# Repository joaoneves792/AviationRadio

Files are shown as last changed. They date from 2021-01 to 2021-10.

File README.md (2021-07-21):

# AviationRadio
Aviation inspired radio using an Arduino + Si4844

It can receive broadcast FM and VHF AM, including the civil aviation airband, (using a downconverter based on SA612 + Si5351)

It also works as a flight sim peripheral, currently with an X-Plane 11 plugin (Linux only) for controlling the plane radios.

# TODO 
- documentation
- BOM
- Redesign the 3D printed box (current printed version is very rough quality)

# Initial working prototype pictures

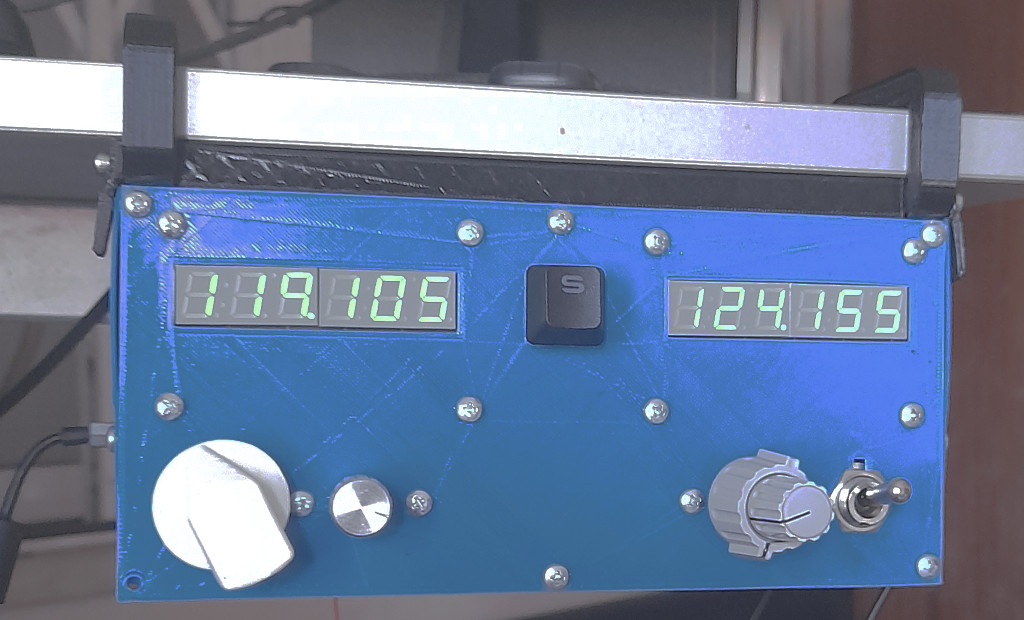
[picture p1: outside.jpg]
outside


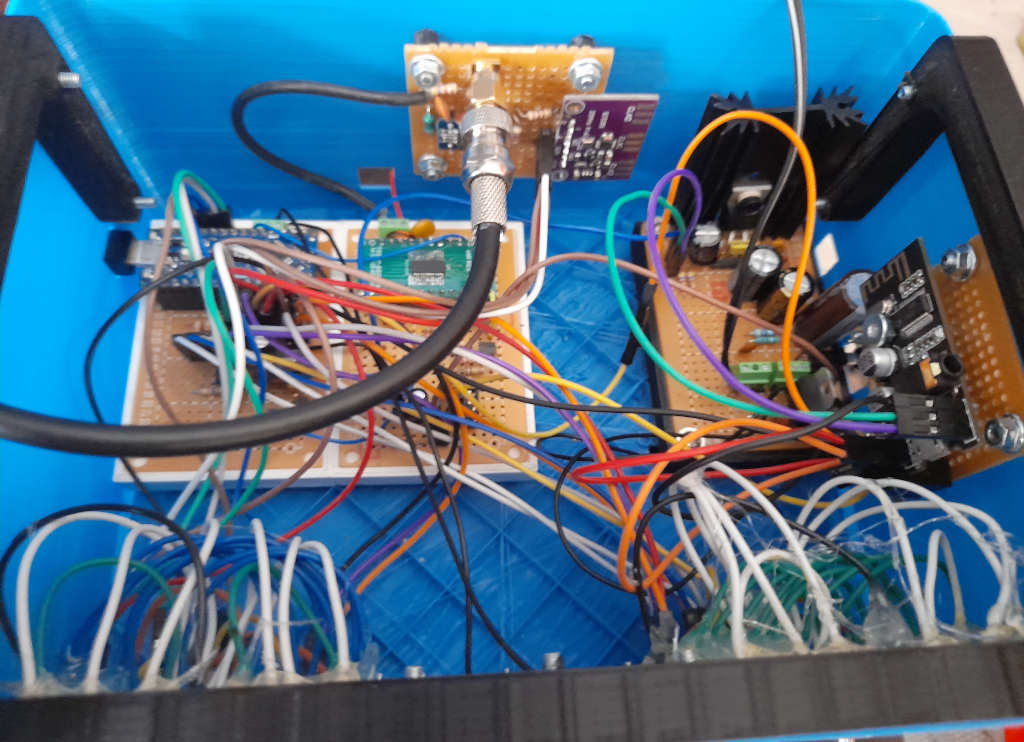
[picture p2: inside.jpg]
inside


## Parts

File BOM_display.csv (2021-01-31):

Name | Type | Value | Quantity | Unit Price | Quant Price | Total BOM Cost
Q1, Q2, Q3, Q4, Q5, Q6 | TO92 | 2N7000 | 6 | 0,10 ? | 0,60 ? | 11,19 ?
IC3 | DIP8 | ATTiny85 | 1 | 2,68 ? | 2,68 ?
Connector1 | Connector: Pin Strip (100 mil) (4 pins) | Connector1 | 1 | 0,10 ? | 0,10 ?
R1 | AngledResistor | 220 | 1 | 0,02 ? | 0,02 ?
IC1, IC2 | DIP16 | 74HC595 | 2 | 0,71 ? | 1,42 ?
7S1, 7S2 | 7SEG | HDSP-433G | 2 | 2,60 ? | 5,20 ?
Board | PerfBoard | PerfBoard | 1 | 1,17 ? | 1,17 ?

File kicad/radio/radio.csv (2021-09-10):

Reference | Quantity | Value
A1 | 1 | Arduino_Nano_Every
C1 C2 C3 C4 C11 | 5 | 10nF
C10 | 1 | 1nF
C12 | 1 | 1uF
C13 | 1 | 100uF
C5 C8 | 2 | 100nF
C6 C7 | 2 | 22pF
C9 | 1 | 470nF
J1 | 1 | SDA
J10 | 1 | GND2/+5v
J2 | 1 | SCL
J3 J4 | 2 | +5v
J5 | 1 | GND1/+12v
J6 | 1 | Audio Out
J7 | 1 | Antennas
J8 J9 | 2 | GND2
JP1 | 1 | Jumper
L1 | 1 | 56nH
Q1 Q2 | 2 | 2N7000
Q3 | 1 | 2N2222
R1 R2 R3 R4 R5 R6 R7 R8 | 8 | 10k
R10 | 1 | 2k
R11 R13 | 2 | 100k
R12 | 1 | 220k
R14 | 1 | 200
R15 | 1 | 10
R16 | 1 | 470
R9 | 1 | 1k
RV1 | 1 | Volume_POT
SW1 | 1 | Cherry MX
SW2 | 1 | SW_Mode_Selection
SW3 SW4 | 1 | ELMA E37
U1 | 1 | Si4844
U2 | 1 | 24LC08
U3 | 1 | 4N35
Y1 | 1 | 32kHz | ~

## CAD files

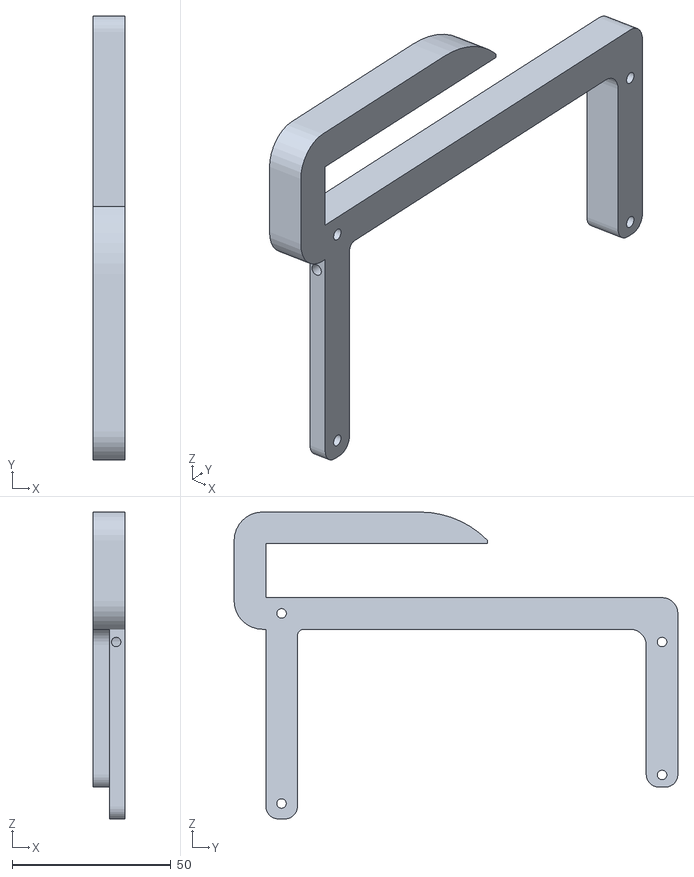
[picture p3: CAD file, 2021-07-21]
3dmodels/support_right.stl
10.0 x 140.0 x 96.8

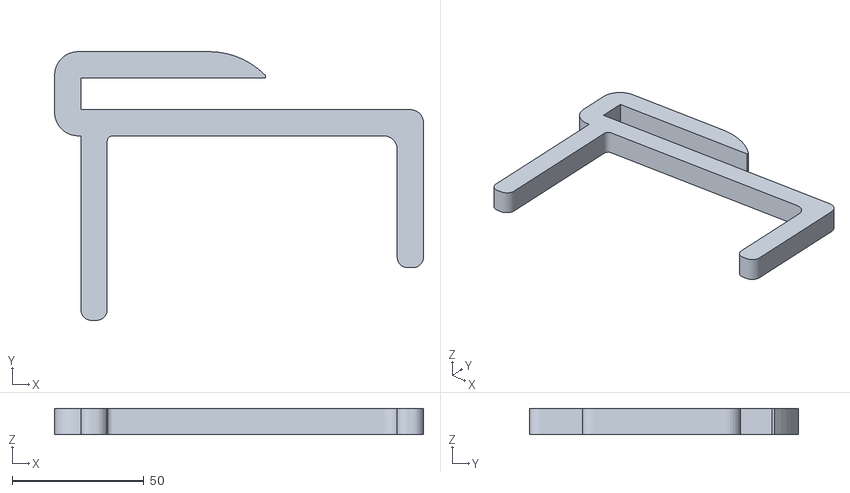
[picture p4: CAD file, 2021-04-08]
3dmodels/supports_cad.stl
140.0 x 102.0 x 10.0

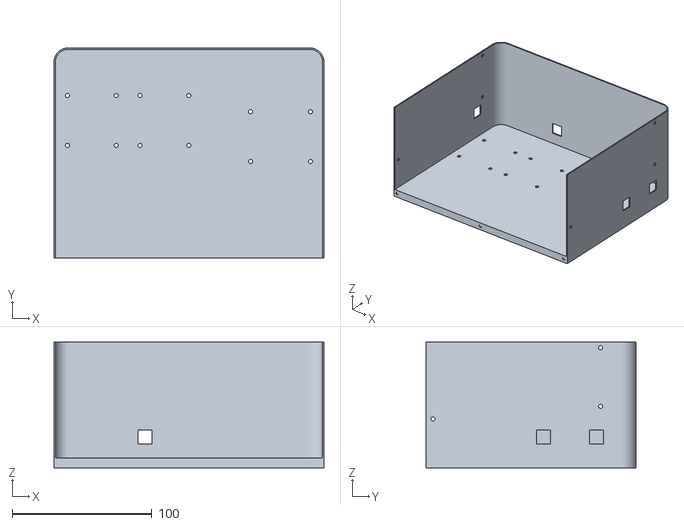
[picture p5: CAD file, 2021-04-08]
3dmodels/box.stl
193.2 x 150.3 x 90.0

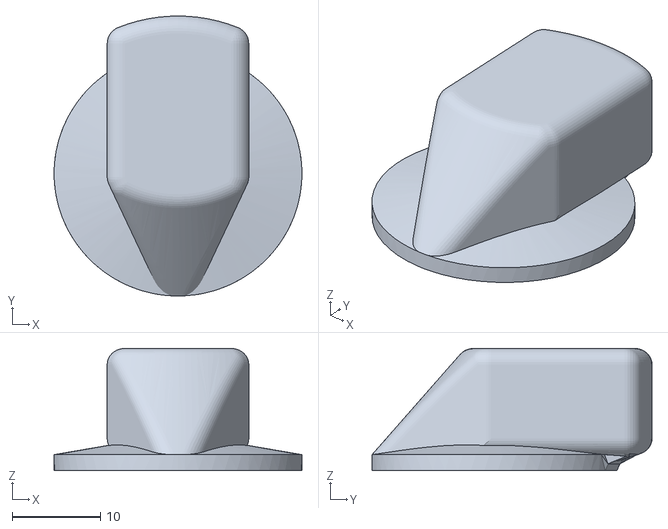
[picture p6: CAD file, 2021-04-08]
3dmodels/ECAM2.stl
28.1 x 31.8 x 13.9

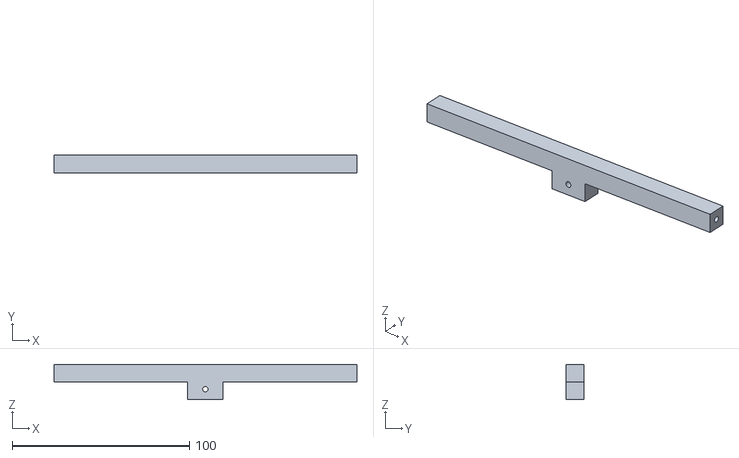
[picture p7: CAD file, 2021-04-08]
3dmodels/strut.stl
171.1 x 10.0 x 19.9

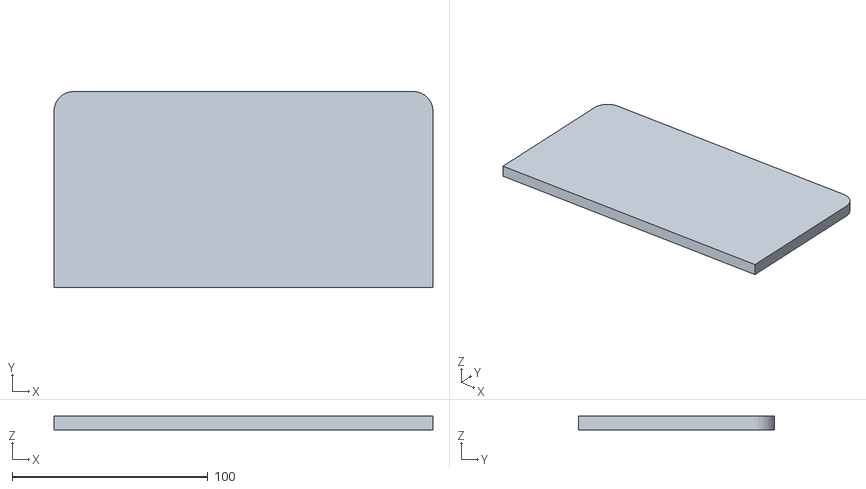
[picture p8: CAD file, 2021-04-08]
3dmodels/boxCAD.stl
193.5 x 100.0 x 7.00

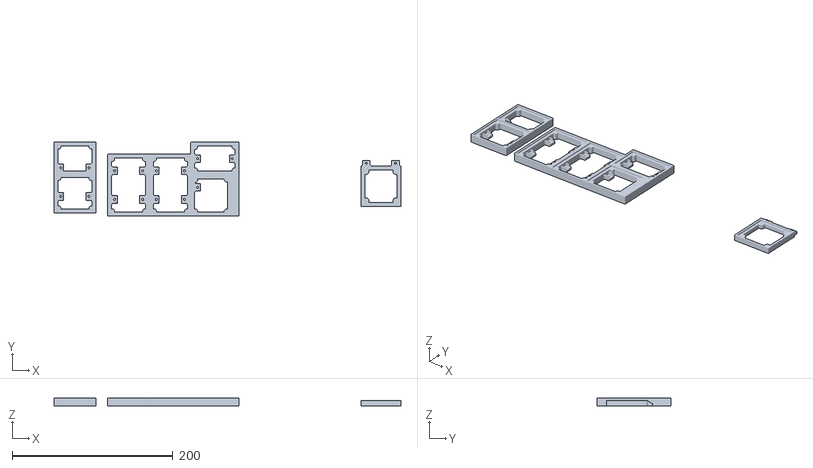
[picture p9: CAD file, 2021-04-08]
3dmodels/PCBholder_WIP.stl
431.3 x 92.3 x 10.0

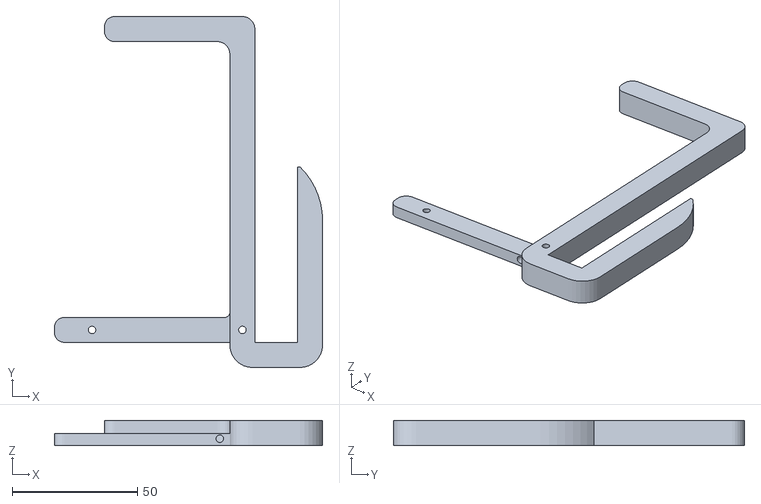
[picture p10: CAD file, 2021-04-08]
3dmodels/supports_blender.stl
107.0 x 140.0 x 10.0

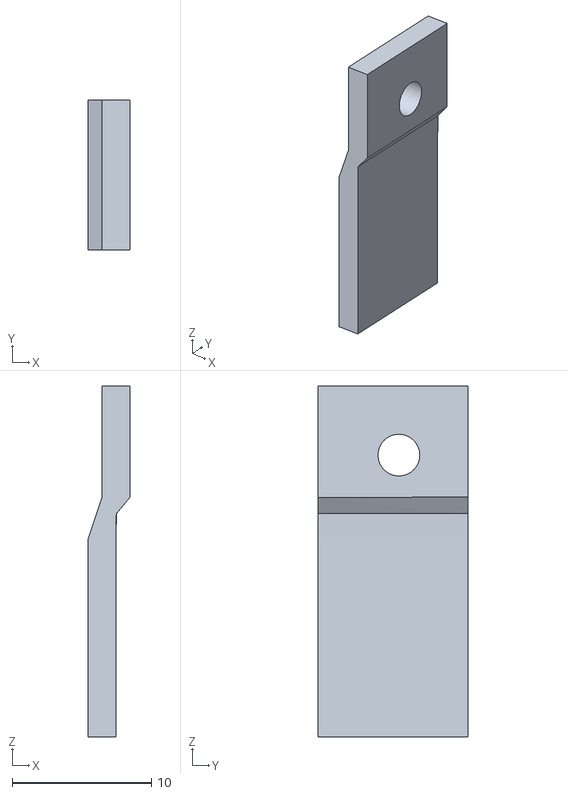
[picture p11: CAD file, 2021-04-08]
3dmodels/Clip.stl
3.00 x 10.8 x 25.2

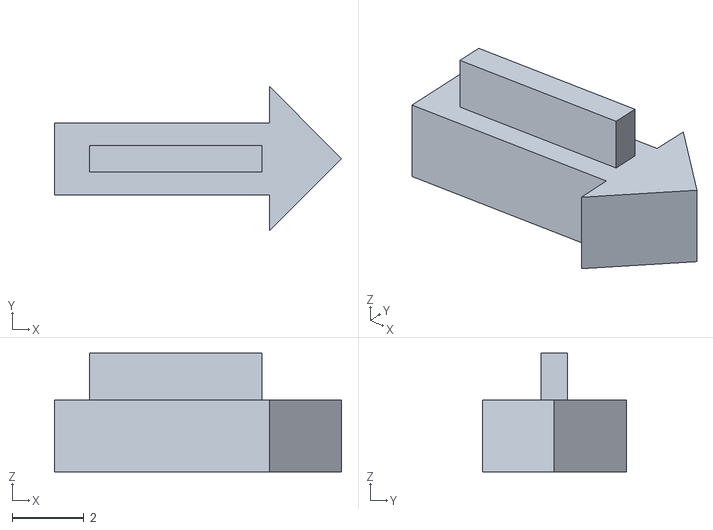
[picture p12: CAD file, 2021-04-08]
3dmodels/Arrow.stl
7.99 x 4.02 x 3.31

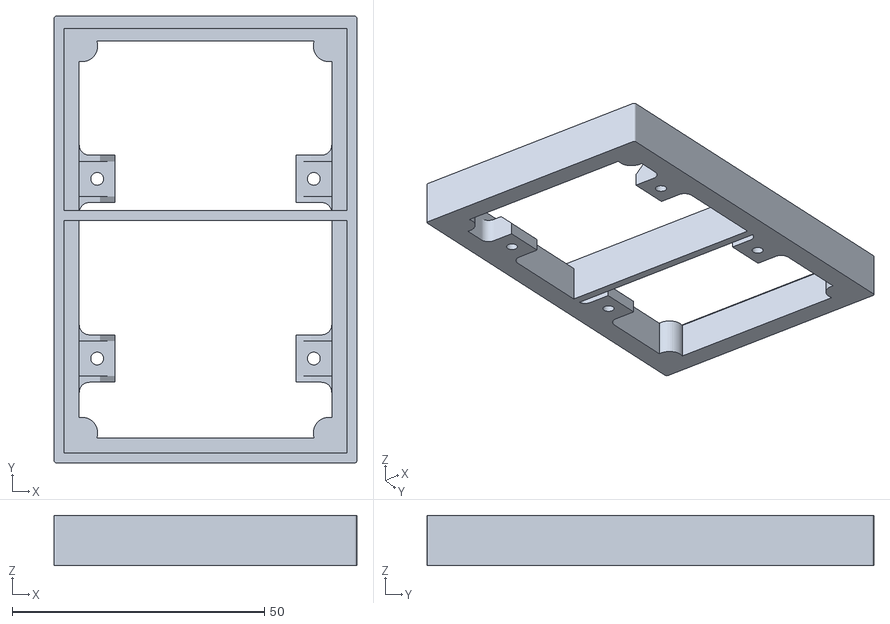
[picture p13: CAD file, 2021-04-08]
3dmodels/PCBholder_AMP_POWER.stl
60.0 x 88.6 x 10.0

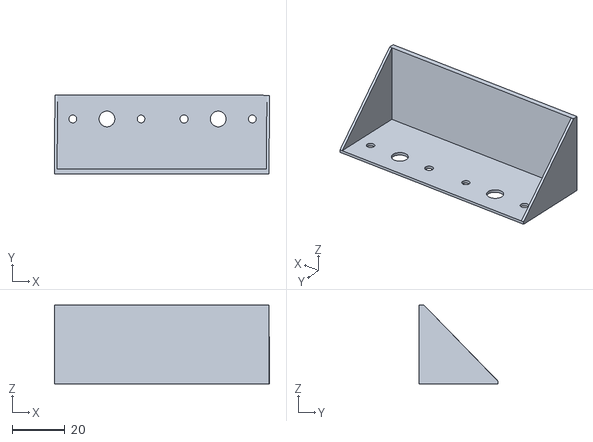
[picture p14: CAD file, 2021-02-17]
3dmodels/testPanel.stl
81.9 x 30.2 x 29.9

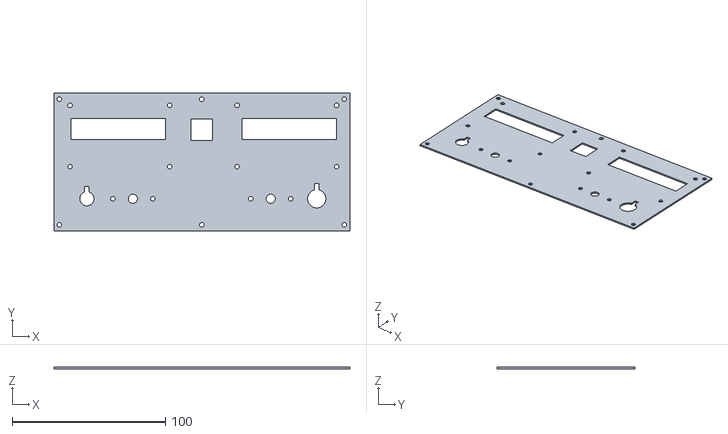
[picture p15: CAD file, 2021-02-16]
3dmodels/frontPanelV2.stl
193.2 x 90.0 x 1.00

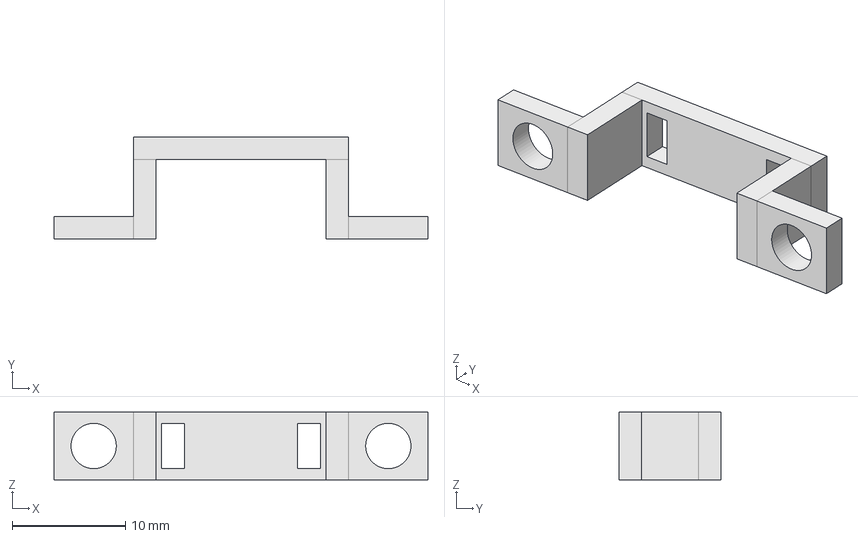
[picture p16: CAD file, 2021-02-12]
3dmodels/EncoderSupport .FCStd
33.0 x 9.00 x 6.00 mm

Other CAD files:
3dmodels/Supports2.FCStd
3dmodels/Supports.FCStd
3dmodels/potSupport.FCStd
3dmodels/MXterst.FCStd
3dmodels/All.blend
3dmodels/EncoderSupport.stl
3dmodels/FrontPanelV1.FCStd
3dmodels/M3Spacer.blend
3dmodels/M3_6mmHex.stl
3dmodels/MXtest.stl
3dmodels/VK_MXtest.3mf
3dmodels/displayTest.FCStd
3dmodels/displayTest.stl
3dmodels/frontPanelV1.stl
3dmodels/potSupport.blend
3dmodels/potSupport.stl

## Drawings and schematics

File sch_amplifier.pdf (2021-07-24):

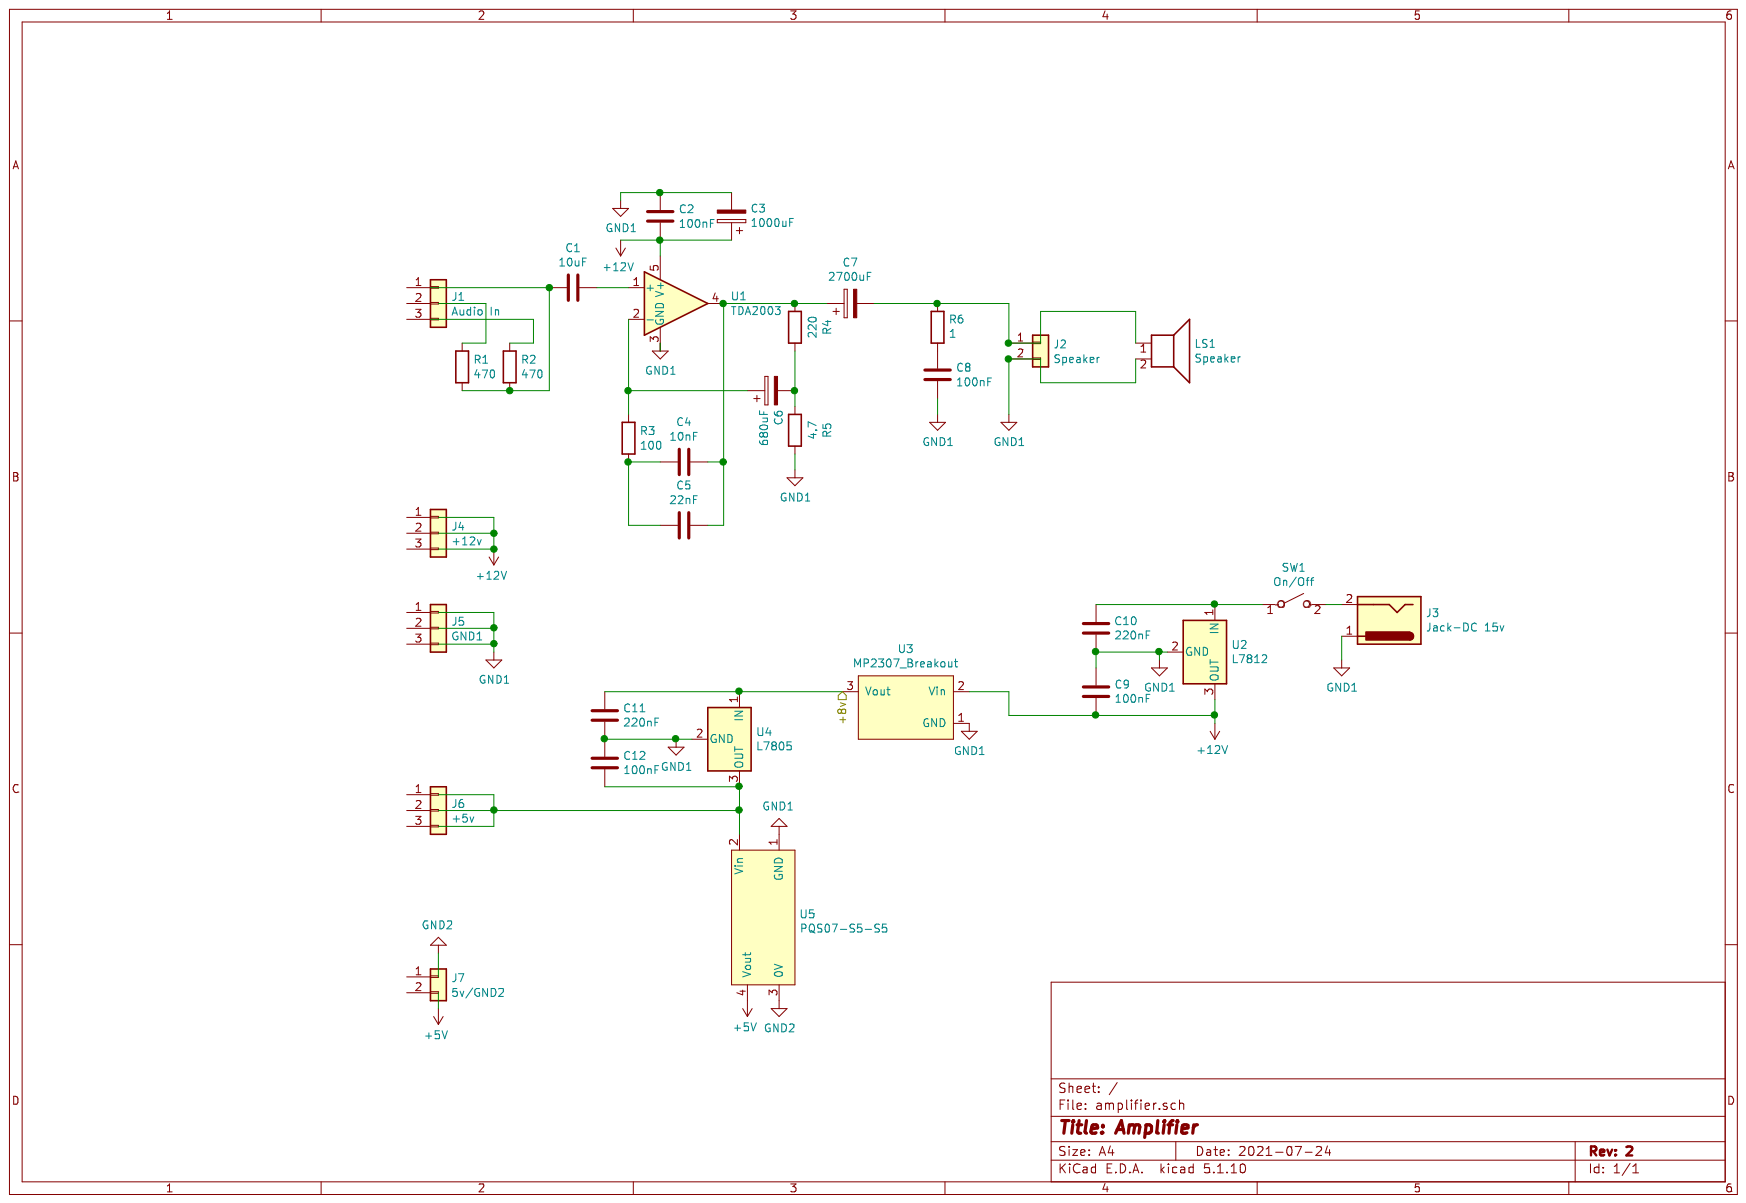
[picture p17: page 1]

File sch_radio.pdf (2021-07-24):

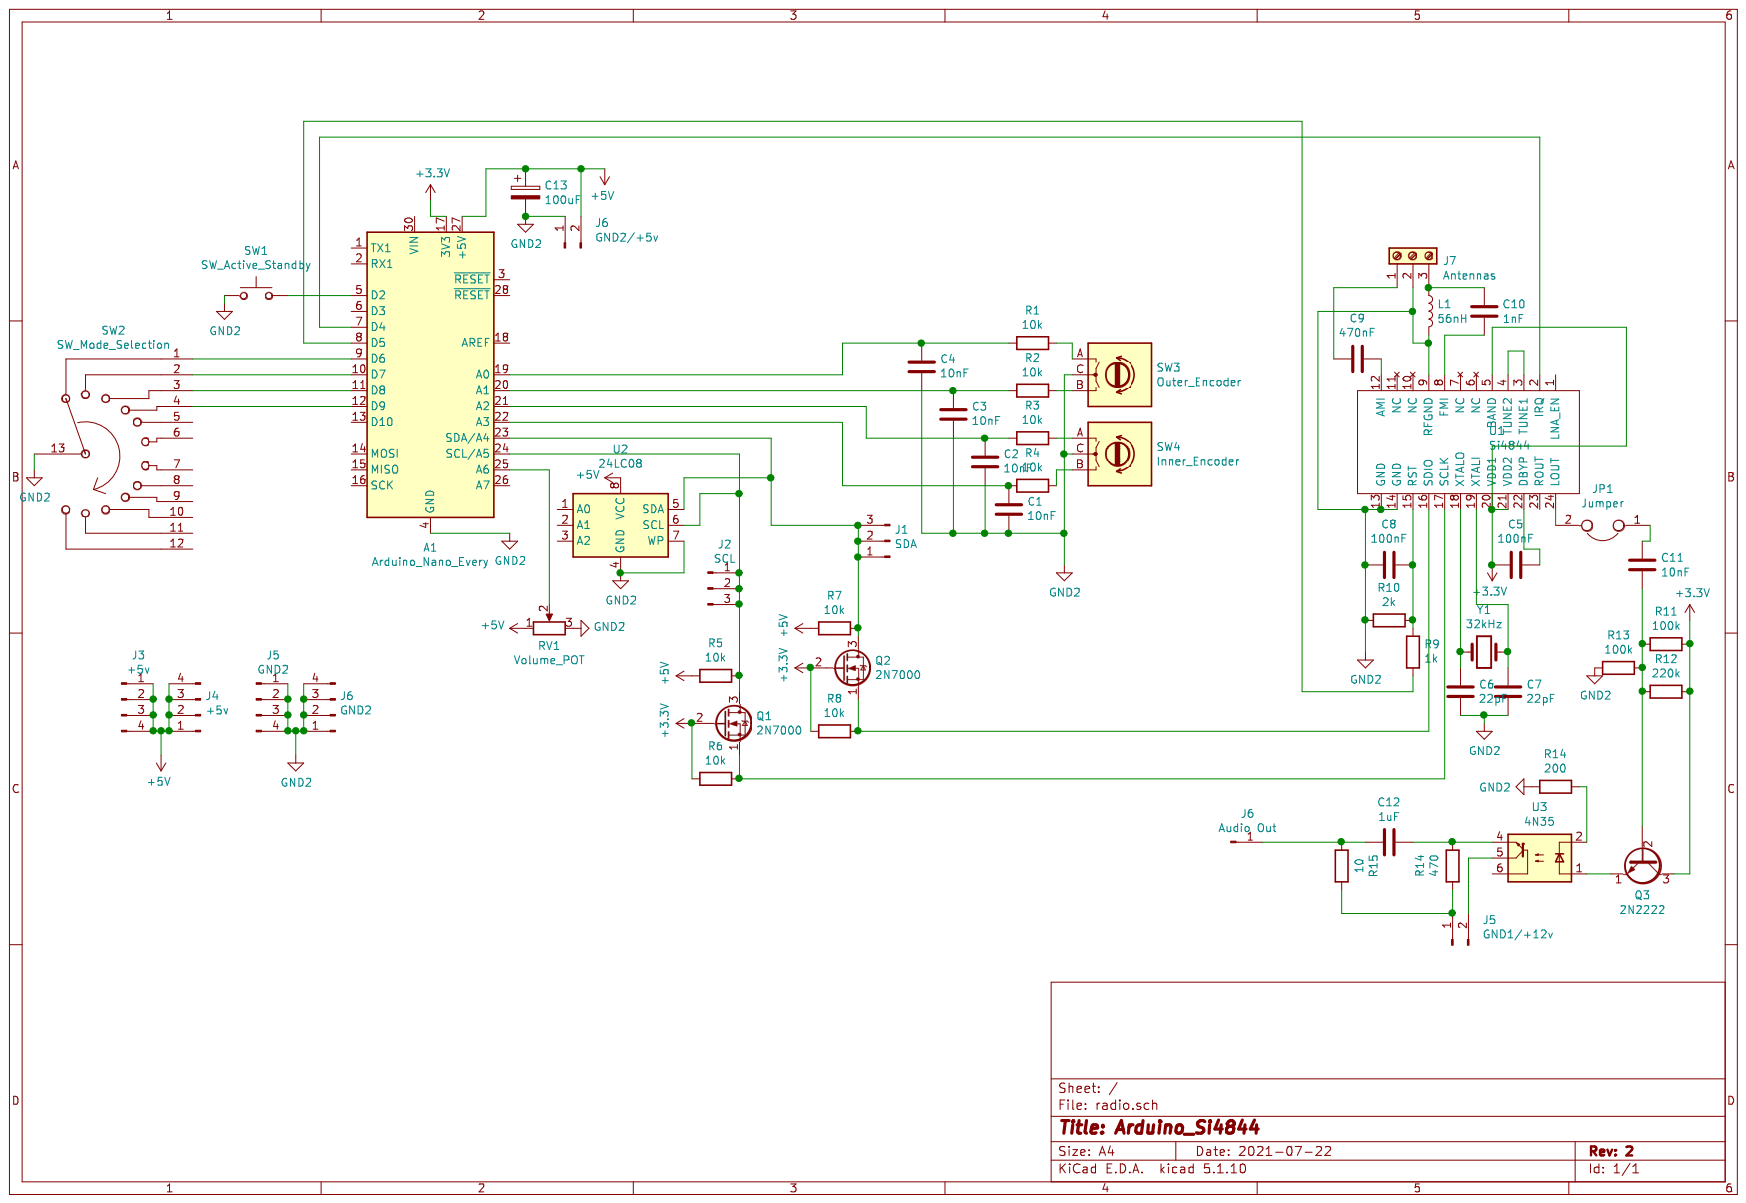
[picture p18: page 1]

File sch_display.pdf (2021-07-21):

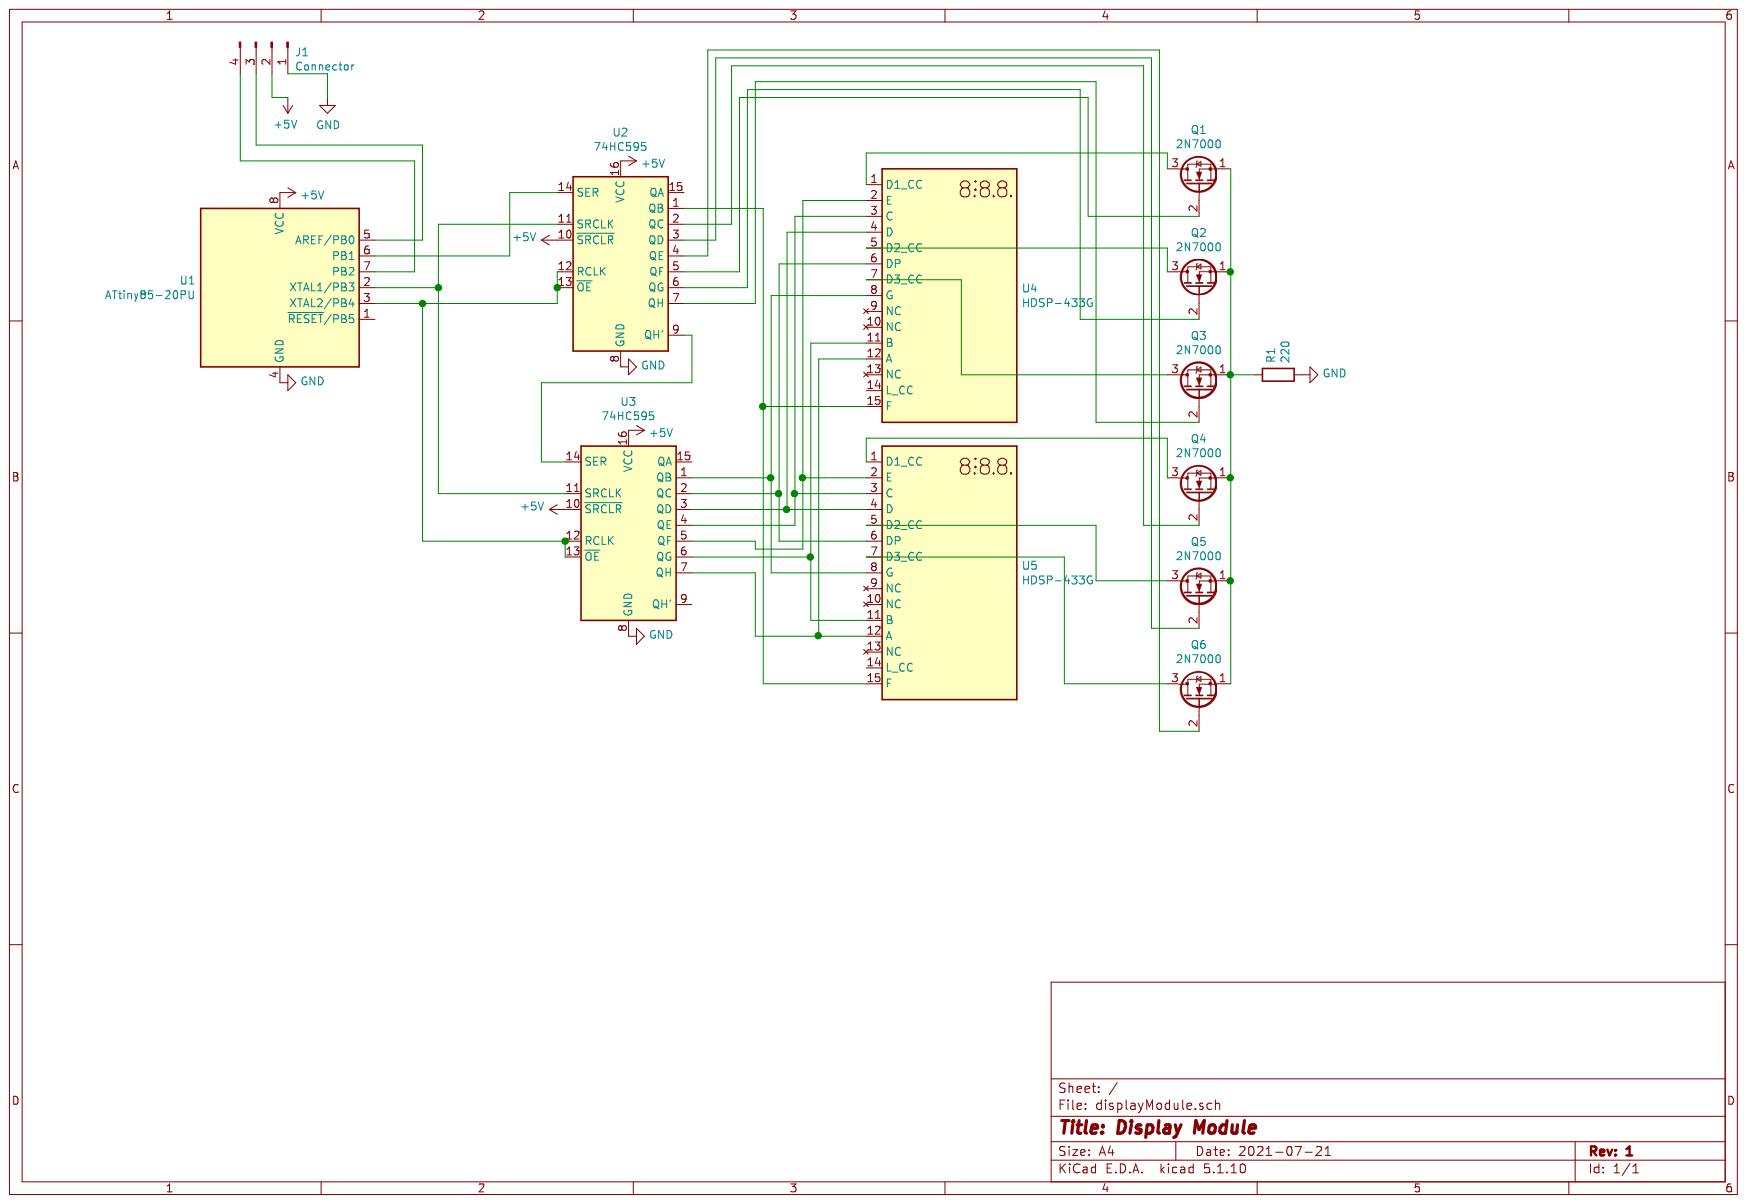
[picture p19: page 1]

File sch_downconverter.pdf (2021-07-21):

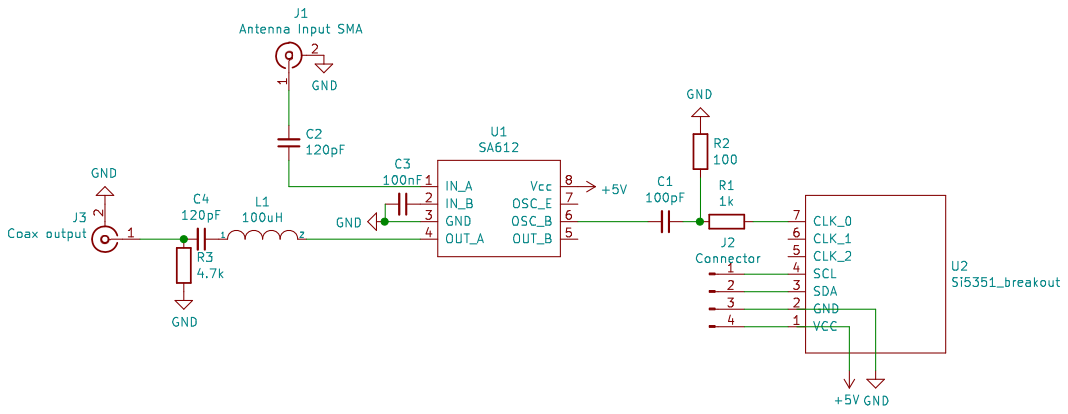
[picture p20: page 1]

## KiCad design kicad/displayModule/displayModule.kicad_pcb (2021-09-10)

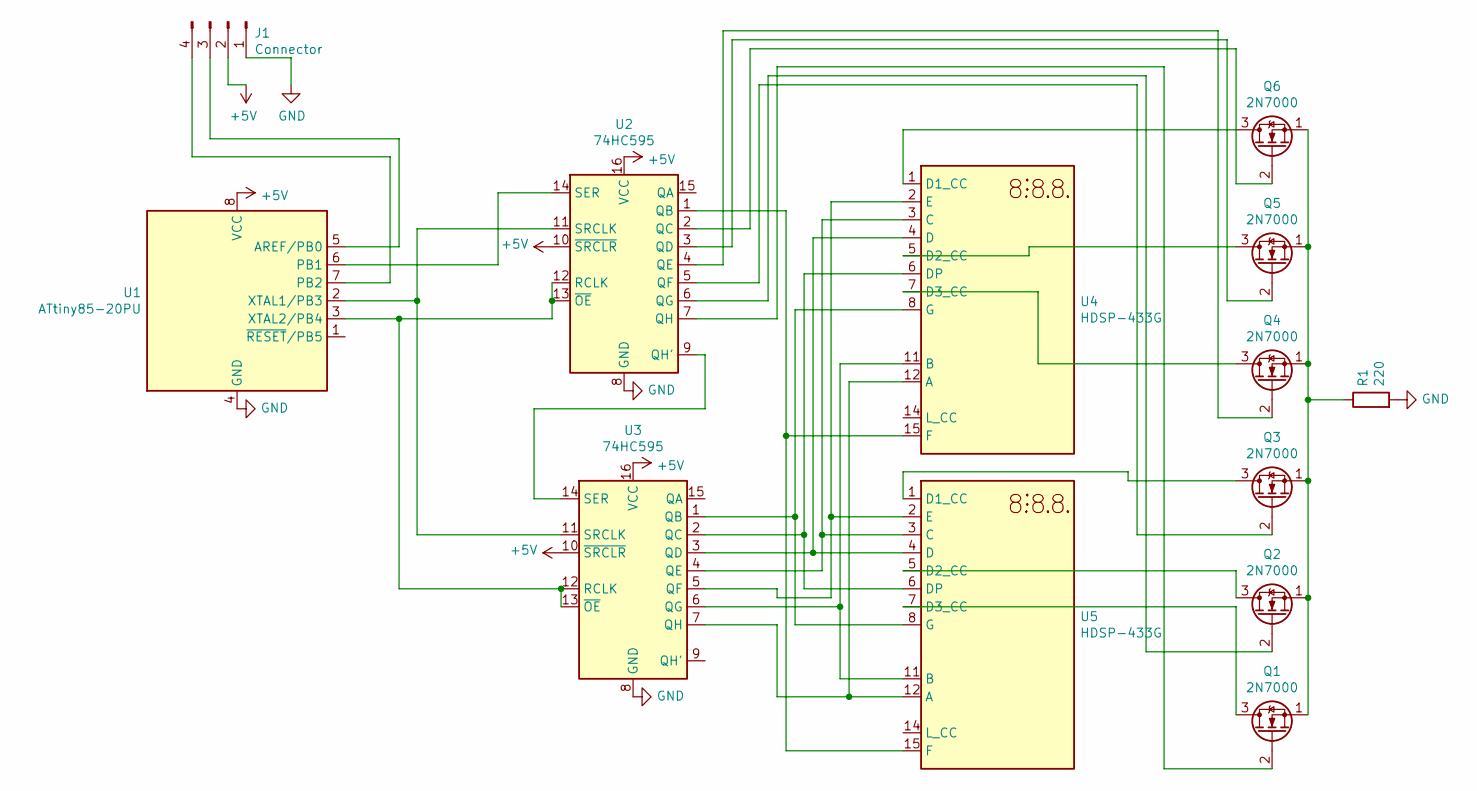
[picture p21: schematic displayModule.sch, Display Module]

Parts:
J1: Connector; PinHeader_1x04_P2.54mm_Vertical
Q1, Q2, Q3, Q4, Q5, Q6: 2N7000; TO-92_Inline_Wide
R1: 220; R_Axial_DIN0207_L6.3mm_D2.5mm_P7.62mm_Horizontal
U1: ATtiny85-20PU; DIP-8_W7.62mm
U2, U3: 74HC595; DIP-16_W7.62mm
U4, U5: HDSP-433G

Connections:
+5V: J1.2, U1.8 (VCC), U2.10 (~SRCLR), U2.16 (VCC), U3.10 (~SRCLR), U3.16 (VCC)
GND: J1.1, R1.2, U1.4 (GND), U2.8 (GND), U3.8 (GND)
unnamed: J1.3, U1.5 (AREF/PB0)
unnamed: J1.4, U1.7 (PB2)
unnamed: Q1.1 (S), Q2.1 (S), Q3.1 (S), Q4.1 (S), Q5.1 (S), Q6.1 (S), R1.1
unnamed: Q1.2 (G), U2.7 (QH)
unnamed: Q1.3 (D), U5.7 (D3_CC)
unnamed: Q2.2 (G), U2.6 (QG)
unnamed: Q2.3 (D), U5.5 (D2_CC)
unnamed: Q3.2 (G), U2.5 (QF)
unnamed: Q3.3 (D), U5.1 (D1_CC)
unnamed: Q4.2 (G), U2.4 (QE)
unnamed: Q4.3 (D), U4.7 (D3_CC)
unnamed: Q5.2 (G), U2.3 (QD)
unnamed: Q5.3 (D), U4.5 (D2_CC)
unnamed: Q6.2 (G), U2.2 (QC)
unnamed: Q6.3 (D), U4.1 (D1_CC)
unnamed: U1.2 (XTAL1/PB3), U2.11 (SRCLK), U3.11 (SRCLK)
unnamed: U1.3 (XTAL2/PB4), U2.12 (RCLK), U2.13 (~OE), U3.12 (RCLK), U3.13 (~OE)
unnamed: U1.6 (PB1), U2.14 (SER)
unnamed: U2.1 (QB), U4.15 (F), U5.15 (F)
unnamed: U2.9 (QH'), U3.14 (SER)
unnamed: U3.1 (QB), U4.8 (G), U5.8 (G)
unnamed: U3.2 (QC), U4.6 (DP), U5.6 (DP)
unnamed: U3.3 (QD), U4.4 (D), U5.4 (D)
unnamed: U3.4 (QE), U4.3 (C), U5.3 (C)
unnamed: U3.5 (QF), U4.2 (E), U5.2 (E)
unnamed: U3.6 (QG), U4.11 (B), U5.11 (B)
unnamed: U3.7 (QH), U4.12 (A), U5.12 (A)

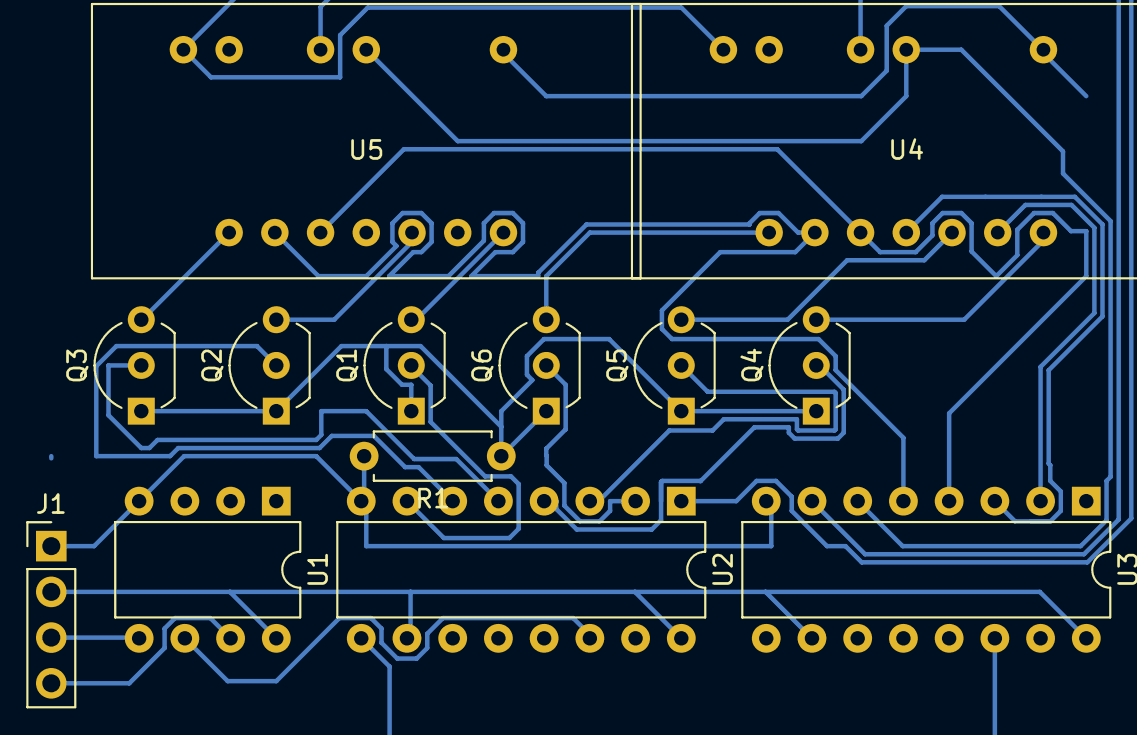
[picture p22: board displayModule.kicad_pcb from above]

Board: 2 copper layers, 13 parts (0 on the bottom side), 29 nets.

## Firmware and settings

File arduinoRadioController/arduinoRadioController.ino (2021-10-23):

#include <Arduino.h>
#include <Wire.h>
#include "si5351.h"
#include "./Encoder.h"
#include <avr/io.h>

#define buttonPin 2 //Pin connected to active/standby button
#define volumePotPin A6
#define FMselectPin 6
#define COMselectPin 7
#define NAVselectPin 8
#define ATDD_RESET_PIN 5
#define ATDD_IRQ_PIN 4

#define OUTER_ENCODER_A_PIN 14
#define OUTER_ENCODER_B_PIN 17
#define INNER_ENCODER_A_PIN 16
#define INNER_ENCODER_B_PIN 15

#define SLAVE_ACTIVE_ADDRESS 0x12
#define SLAVE_STNDBY_ADDRESS 0x13
#define ATDD_ADDRESS 0x11
#define EPROM_ADDRESS 0x50
#define LO_ADDRESS 0x60

#define ACTIVE_MEMSLOT 0
#define STANDBY_MEMSLOT 1

#define FM_MODE 0
#define AM_MODE 1
#define SW_MODE 2
#define COM_MODE 3
#define NAV_MODE 4
#define COM2_MODE 5

#define ENCODER_CONTROLLS_STANDBY
//#undef ENCODER_CONTROLLS_STANDBY

#define RX_HARD_MUTE 0x4001
#define RX_BASS_TREBLE 0x4002
#define AM_SOFT_MUTE_SLOPE 0x3301
#define AM_SOFT_MUTE_MAX_ATTENUATION 0x3302
#define AM_SOFT_MUTE_SNR_THRESHOLD 0x3303
#define AM_SOFT_MUTE_RATE 0x3300
#define AM_SQUELCH_SNR_THRESHOLD 7


// IF in kHz
#define IF 1200
#define LO_PPM 146391

const unsigned char digitSegments[16]  = {
                 0b11111100,//0
                 0b01100000,//1
                 0b11011010,//2
                 0b11110010,//3
                 0b01100110,//4
                 0b10110110,//5
                 0b00111110,//6
                 0b11100000,//7
                 0b11111110,//8
                 0b11100110,//9
                 0b11101110,//A
                 0b00111110,//B
                 0b10011100,//C 
                 0b01111010,//D 
                 0b10011110,//E 
                 0b10001110,//F
                };

typedef struct{
  uint16_t MHz;
  uint16_t kHz;
} freq;
#define SET_FREQ(FREQ, STRUCT) {STRUCT.MHz = FREQ/1000; STRUCT.kHz = FREQ%1000;}
#define GET_FREQ(STRUCT) ((uint32_t)(STRUCT.MHz)*1000+STRUCT.kHz)

struct setPropertyQueueElement;
struct setPropertyQueueElement{
  uint16_t property;
  uint16_t value;
  struct setPropertyQueueElement* next;
};


/*-----------------------*/
//Global variables (shared memory between all threads)
freq shm_activeFreq;
freq shm_standbyFreq;
struct setPropertyQueueElement* shm_propertiesQueue = NULL;
uint8_t shm_bandmode = 0;
volatile uint8_t shm_ATDDIRQ = 0;
uint8_t shm_ATDDOperational = 0;
uint8_t shm_ATDDReady = 0;
uint8_t shm_AMStationDetected = 0;
uint8_t shm_scanInProgress = 0;
Si5351 shm_si5351(LO_ADDRESS);
/*-----------------------*/

/*------------------------*/
Encoder* outerEncoder = NULL;
Encoder* innerEncoder = NULL;
/*------------------------*/

/*------------------------*/
/* property queue*/
void queueProperty(uint16_t property, uint16_t value) {
  struct setPropertyQueueElement* prev = shm_propertiesQueue;
  while(prev && prev->next){
    prev = prev->next;
  }
  struct setPropertyQueueElement* prop = (struct setPropertyQueueElement*) malloc(sizeof(struct setPropertyQueueElement));
  prop->property = property;
  prop->value = value;
  prop->next = NULL;
  if(NULL == prev){
    shm_propertiesQueue = prop;
  }else{
    prev->next = prop;
  }
 }
/*-----------------------*/

/*-----------------------*/
//Thread handling
struct thread;
struct thread {
  void (*function)();
  short target;
  unsigned long lastExecuted;
  struct thread* next;
};

struct thread* threads;

struct thread* createNewThread(void (*function)(), short target){
  struct thread* newThread = (thread*)malloc(sizeof(thread));

  newThread->function = function;
  newThread->target = target;
  newThread->lastExecuted = 0;
  newThread->next =NULL;

  return newThread;  
}

void insertThread(struct thread* t){
  t->next = threads;
  threads = t;
}
/*-----------------------*/

/*-----------------------*/
//EEPROM commands

void EEPROMwrite(uint32_t freq, uint8_t mode, uint8_t active){
  uint8_t address = mode*8+active*4;
  do{
    Wire.beginTransmission(EPROM_ADDRESS);
    Wire.write(address);
    Wire.write((freq >> 24) & 0xff);
    Wire.write((freq >> 16) & 0xff);
    Wire.write((freq >> 8) & 0xff);
    Wire.write(freq & 0xff);
  }while(Wire.endTransmission());
}

uint32_t EEPROMread(uint8_t mode, uint8_t active){
  uint8_t address = mode*8+active*4;
  do{
    Wire.beginTransmission(EPROM_ADDRESS);
    Wire.write(address);
  }while(Wire.endTransmission(false));
  Wire.requestFrom(EPROM_ADDRESS, 4);
  while(Wire.available() < 4){delay(5);}
  uint32_t f =   ((uint32_t)Wire.read() << 24) 
          |((uint32_t)Wire.read() << 16) 
          |((uint32_t)Wire.read() << 8) 
          | Wire.read();
  return f;
}

/*-----------------------*/


/*-----------------------*/
//ATDD commands

uint16_t ATDD_FREQ_TO_INT_FM(uint16_t ATDD_freq){
  return ((ATDD_freq & 0x0f)+((ATDD_freq & 0xf0)>>4)*10+((ATDD_freq & 0xf00)>>8)*100+((ATDD_freq & 0xf000)>>12)*1000)*10;
}
uint16_t ATDD_FREQ_TO_INT_AM(uint16_t ATDD_freq){
  return ((ATDD_freq & 0x0f)+((ATDD_freq & 0xf0)>>4)*10+((ATDD_freq & 0xf00)>>8)*100+((ATDD_freq & 0xf000)>>12)*1000);
}


void ATDD_SET_PROPERTY(uint16_t propertyNumber, uint16_t parameter)
{
  if(!shm_ATDDOperational || !shm_ATDDReady)
    return;

  shm_ATDDReady = 0;

#define SET_PROPERTY 0x12
    Wire.beginTransmission(ATDD_ADDRESS);
    Wire.write(SET_PROPERTY);
    Wire.write(0x00);
    Wire.write(propertyNumber >> 8); // Send property - High byte - most significant first
    Wire.write(propertyNumber & 0xff);  // Send property - Low byte - less significant after
    Wire.write(parameter >> 8);    // Send the argments. High Byte - Most significant first
    Wire.write(parameter & 0xff);     // Send the argments. Low Byte - Less significant after
    Wire.endTransmission();

    do{
      delay(2);
      ATDD_GET_STATUS();
    }while(!shm_ATDDReady);
}


void ATDD_RESET(){
  shm_ATDDOperational = 0;
  shm_ATDDReady = 0;
  digitalWrite(LED_BUILTIN, LOW);
  digitalWrite(ATDD_RESET_PIN, LOW);
  delay(200);
  digitalWrite(ATDD_RESET_PIN, HIGH);
}

void ATDD_POWERUP(){
#define ATDD_POWER_UP_CMD 0xE1
    uint8_t band;
    uint8_t chspc;

    if(shm_bandmode != FM_MODE && shm_bandmode != AM_MODE && shm_bandmode != SW_MODE){
      band = 2;
      chspc = 1;
    }
    

    if(shm_bandmode == FM_MODE){
      band = 2;
      chspc = 1;
    }
    else if (shm_bandmode == AM_MODE){
      band = 20;
      chspc = 1;
      //band = 25; //SW bandmode
      //chspc = 5;
    }

    shm_ATDDReady = 0;

    uint16_t freq = (GET_FREQ(shm_activeFreq)/((shm_bandmode==FM_MODE)?10:1));

    uint8_t args[7];

    args[0] = 0x80; //Enable crystal
    //args[0] = 0x0; //Disable crystal
    args[0] |= band;
    if(shm_bandmode == FM_MODE){
      args[1] = (freq-chspc) >> 8;
      args[2] = (freq-chspc) & 0xff;

      args[3] = (freq) >> 8;
      args[4] = (freq) & 0xff;
    }else if(shm_bandmode == AM_MODE){
      args[1] = (IF-(50*chspc)) >> 8;
      args[2] = (IF-(50*chspc)) & 0xff;

      args[3] = (IF) >> 8;
      args[4] = (IF) & 0xff;

    }

    args[5] = chspc;

    args[6] = 0x1 << 6;

    Wire.beginTransmission(ATDD_ADDRESS);
    Wire.write(ATDD_POWER_UP_CMD);
    Wire.write(args[0]);
    Wire.write(args[1]);
    Wire.write(args[2]);
    Wire.write(args[3]);
    Wire.write(args[4]);
    Wire.write(args[5]);
    Wire.write(args[6]);
    Wire.endTransmission();
    delay(3);//the host controller needs to wait for 2 ms before polling response byte CTS bit or reading the response directly.

    //ATDD_SET_PROPERTY(0x0201, 0x7c9c); //Set clock to 31900
    //ATDD_SET_PROPERTY(0x0202, 500); //Set divider to 500
    
}

void ATDD_GET_STATUS(){
#define ATDD_GET_STATUS_CMD (0xE0)
#define CTS_BIT_MASK (1 << 7) 
#define HOSTRST_BIT_MASK (1 << 6)
#define HOSTPWRUP_BIT_MASK (1 << 5)
#define INFORDY_BIT_MASK (1 << 4)
#define STATION_BIT_MASK (1 << 3)
#define STEREO_BIT_MASK (1 << 2)
#define BCFG1_BIT_MASK (1 << 1)
#define BCFG0_BIT_MASK (1 << 0)
#define GET_BAND_MODE(resp) ((resp & 0xC0) >> 6)
#define GET_BANDIDX(resp) (resp & 0x3f)


    Wire.beginTransmission(ATDD_ADDRESS);
    Wire.write(ATDD_GET_STATUS_CMD);
    Wire.endTransmission();
    delay(3);//the host controller needs to wait for 2 ms before polling response byte CTS bit or reading the response directly.
    if(!Wire.requestFrom(ATDD_ADDRESS, 4))
      return;
    uint8_t status = Wire.read();
    uint8_t resp1 = Wire.read();
    uint8_t resp2 = Wire.read();
    uint8_t resp3 = Wire.read();
    
    if(status & HOSTRST_BIT_MASK){
      Serial.println("ATDD: Requested reset");
      ATDD_RESET();
      return;
    }

    if(status & HOSTPWRUP_BIT_MASK && (shm_bandmode == FM_MODE || shm_bandmode == AM_MODE)){
      Serial.println("ATDD: Requested powerup");
      ATDD_POWERUP();
      return;
    }
    
    if(status & INFORDY_BIT_MASK){
      if(!shm_ATDDOperational){
        if(shm_bandmode == FM_MODE){
          queueProperty(RX_BASS_TREBLE, 1);
          queueProperty(RX_HARD_MUTE, 0x0);
        }else if(shm_bandmode == AM_MODE){
          queueProperty(RX_BASS_TREBLE, 1);
          queueProperty(RX_HARD_MUTE, 0x0);
        }
      }
      shm_ATDDOperational = 1;
      digitalWrite(LED_BUILTIN, HIGH);
      Serial.print("ATDD: Frequency: ");
      if(shm_bandmode == FM_MODE)
        Serial.print(ATDD_FREQ_TO_INT_FM(((uint16_t)resp2 << 8) | resp3));
      else
        Serial.print(ATDD_FREQ_TO_INT_AM((uint16_t)resp2 << 8 | resp3));
      
      Serial.print("KHz");
      Serial.print(" Station ");
      if(shm_scanInProgress && (status & STATION_BIT_MASK)){
        shm_scanInProgress = 0;
      }
      (status & STATION_BIT_MASK)?Serial.print("valid"):Serial.print("invalid");
      if(!shm_AMStationDetected && (status & STATION_BIT_MASK)){
        shm_AMStationDetected = 1;
        //Set squelch
        queueProperty(AM_SOFT_MUTE_SNR_THRESHOLD, AM_SQUELCH_SNR_THRESHOLD);
        queueProperty(AM_SOFT_MUTE_SLOPE, 5);
        queueProperty(AM_SOFT_MUTE_MAX_ATTENUATION, 63); 
        queueProperty(AM_SOFT_MUTE_RATE, 255);
      }

      Serial.print(" Stereo ");
      (status & STEREO_BIT_MASK)?Serial.print("on"):Serial.print("off");
      Serial.print(" Band: ");
      if(GET_BAND_MODE(resp1) == 0)
        Serial.print("FM");
      if(GET_BAND_MODE(resp1) == 1)
        Serial.print("AM");
      if(GET_BAND_MODE(resp1) == 2)
        Serial.print("SW");
      Serial.println("");
      
    }
    shm_ATDDReady = (status & CTS_BIT_MASK);
    
}

void ATDDIHR(){
  shm_ATDDIRQ=1;
  //Serial.println("IRQ");
} 


void onFreqChange(){
  if(shm_bandmode == AM_MODE){
    shm_AMStationDetected = 0;
    //Set defaults
    queueProperty(AM_SOFT_MUTE_SNR_THRESHOLD, 0x0008);
    queueProperty(AM_SOFT_MUTE_SLOPE, 0x0001);
    queueProperty(AM_SOFT_MUTE_MAX_ATTENUATION, 0x0010); 
    queueProperty(AM_SOFT_MUTE_RATE, 0x0040);
  }

  printChange();
}

/*-----------------------------*/
void printChange(){
  Serial.print("AVRADIO ");
  Serial.print("A:");
  Serial.print(GET_FREQ(shm_activeFreq));
  Serial.print(" S:");
  Serial.print(GET_FREQ(shm_standbyFreq));
  Serial.print(" M:");
  Serial.print(shm_bandmode);
  Serial.println("");
}


void updateDisplays(){
  static uint32_t lastActiveFreq = 0;
  static uint32_t lastStandbyFreq = 0;

  if(lastActiveFreq != GET_FREQ(shm_activeFreq)){
    Wire.beginTransmission(SLAVE_ACTIVE_ADDRESS);
    Wire.write(0);
    Wire.write(digitSegments[(GET_FREQ(shm_activeFreq) / 100000) % 10]);
    Wire.write(1);
    Wire.write(digitSegments[(GET_FREQ(shm_activeFreq) / 10000) % 10]);
    Wire.write(2);
    Wire.write(digitSegments[(GET_FREQ(shm_activeFreq) / 1000) % 10] | 0x1);
    Wire.write(3);
    Wire.write(digitSegments[(GET_FREQ(shm_activeFreq) / 100) % 10]);
    Wire.write(4);
    Wire.write(digitSegments[(GET_FREQ(shm_activeFreq)/ 10) % 10]);
    Wire.write(5);
    Wire.write(digitSegments[(GET_FREQ(shm_activeFreq)/ 1) % 10]);
    Wire.endTransmission();
    lastActiveFreq = GET_FREQ(shm_activeFreq);
  }
  if(lastStandbyFreq != GET_FREQ(shm_standbyFreq)){
    Wire.beginTransmission(SLAVE_STNDBY_ADDRESS);
    Wire.write(0);
    Wire.write(digitSegments[(GET_FREQ(shm_standbyFreq) / 100000) % 10]);
    Wire.write(1);
    Wire.write(digitSegments[(GET_FREQ(shm_standbyFreq) / 10000) % 10]);
    Wire.write(2);
    Wire.write(digitSegments[(GET_FREQ(shm_standbyFreq) / 1000) % 10] | 0x1);
    Wire.write(3);
    Wire.write(digitSegments[(GET_FREQ(shm_standbyFreq) / 100) % 10]);
    Wire.write(4);
    Wire.write(digitSegments[(GET_FREQ(shm_standbyFreq) / 10) % 10]);
    Wire.write(5);
    Wire.write(digitSegments[(GET_FREQ(shm_standbyFreq) / 1) % 10]);
    Wire.endTransmission();
    lastStandbyFreq = GET_FREQ(shm_standbyFreq);
  }
     
}

void checkVolumePot(){
#define potToDigit() ((uint16_t)(analogRead(volumePotPin)))
  static uint16_t prevVolume = 0;
  static uint16_t average = potToDigit();

  if(!shm_ATDDOperational || !shm_ATDDReady)
    return;

  average -= average/10;
  average += potToDigit()/10;

  uint16_t volume = map(average, 200, 1023, 20, 63);
  //uint16_t volume = map(average, 0, 1023, 0, 30);
  if(prevVolume != volume){
   Serial.println(volume);
#define RX_VOLUME 0x4000
   ATDD_SET_PROPERTY(RX_VOLUME, volume);
   //shm_ATDDReady = 0;
   prevVolume = volume;
  }

}

void readEncoder(){
  uint32_t innerEncoderRead = innerEncoder->read()%1000;
#ifdef ENCODER_CONTROLLS_STANDBY 
  if(innerEncoderRead != shm_standbyFreq.kHz){
    shm_standbyFreq.kHz = innerEncoderRead;
#else
  if(innerEncoderRead != shm_activeFreq.kHz){
    shm_activeFreq.kHz = innerEncoderRead;
#endif
    onFreqChange();
    //We are only changing standby freq, so no need for powerup
#ifndef ENCODER_CONTROLLS_STANDBY
    if(shm_bandmode == FM_MODE)
      ATDD_POWERUP();
    else{
      uint64_t LO = GET_FREQ(shm_activeFreq)*SI5351_FREQ_MULT*1000 - IF*SI5351_FREQ_MULT*1000;
      shm_si5351.set_freq(LO, SI5351_CLK0);
    }
#endif
  }
  uint32_t outerEncoderRead = outerEncoder->read()%1000;
#ifdef ENCODER_CONTROLLS_STANDBY
  if(outerEncoderRead != shm_standbyFreq.MHz){
    shm_standbyFreq.MHz = outerEncoderRead;
#else
  if(outerEncoderRead != shm_activeFreq.MHz){
    shm_activeFreq.MHz = outerEncoderRead;
#endif
    onFreqChange();
#ifndef ENCODER_CONTROLLS_STANDBY
    if(shm_bandmode == FM_MODE)
      ATDD_POWERUP();
    else{
      uint64_t LO = GET_FREQ(shm_activeFreq)*SI5351_FREQ_MULT*1000 - IF*SI5351_FREQ_MULT*1000;
      shm_si5351.set_freq(LO, SI5351_CLK0);
    }
#endif
  }
}

void buttonDebounce(){
#define DEBOUNCE_DELAY 50
  static uint8_t lastFlickerableState = HIGH;
  static uint8_t lastStableState = HIGH;
  static unsigned long lastDebounceTime = 0;
  uint8_t currentState = digitalRead(buttonPin);

  if(currentState != lastFlickerableState){
    lastDebounceTime = millis();
    lastFlickerableState = currentState;
  }

  if((millis()-lastDebounceTime) > DEBOUNCE_DELAY){
    if(lastStableState == LOW && currentState == HIGH){
      uint16_t tmpFreqMHz = shm_activeFreq.MHz;
      uint16_t tmpFreqkHz = shm_activeFreq.kHz;
      SET_FREQ(GET_FREQ(shm_standbyFreq), shm_activeFreq);
      shm_standbyFreq.MHz = tmpFreqMHz;
      shm_standbyFreq.kHz = tmpFreqkHz;
#ifdef ENCODER_CONTROLLS_STANDBY
      innerEncoder->write(shm_standbyFreq.kHz);
      outerEncoder->write(shm_standbyFreq.MHz);
#else
      innerEncoder->write(shm_activeFreq.kHz);
      outerEncoder->write(shm_activeFreq.MHz);
#endif
      onFreqChange();
      if(shm_bandmode == FM_MODE){
        ATDD_POWERUP();
      }else if(shm_bandmode == AM_MODE){
        uint64_t LO = GET_FREQ(shm_activeFreq)*SI5351_FREQ_MULT*1000 - IF*SI5351_FREQ_MULT*1000;
        shm_si5351.set_freq(LO, SI5351_CLK0);
      }


      lastStableState = HIGH;
    }else if (lastStableState == HIGH && currentState == LOW){
      lastStableState = LOW;
    }
  }
}


void checkATTD(){
  if(shm_ATDDIRQ){
    ATDD_GET_STATUS();
    shm_ATDDIRQ = 0;
  }   
  
}

void checkEEPROM(){
  static uint32_t activeFreq = -1;
  static uint32_t standbyFreq = -1;
  if(
    (activeFreq != GET_FREQ(shm_activeFreq)) ||
    (standbyFreq != GET_FREQ(shm_standbyFreq))    
    ){
    activeFreq = GET_FREQ(shm_activeFreq);
    standbyFreq = GET_FREQ(shm_standbyFreq);
    EEPROMwrite(GET_FREQ(shm_standbyFreq), shm_bandmode, STANDBY_MEMSLOT);
    EEPROMwrite(GET_FREQ(shm_activeFreq), shm_bandmode, ACTIVE_MEMSLOT);
  }

}

void checkMode(){
  static uint8_t currentBandMode = -1;
  uint8_t encoderSteps = 1;
  if(shm_bandmode == AM_MODE){
    encoderSteps = 1;
  }

  if(!digitalRead(FMselectPin)){
    shm_bandmode = FM_MODE;
    encoderSteps = 100;
  }else if(!digitalRead(COMselectPin)){
    shm_bandmode = COM_MODE;
    encoderSteps = 5;
  }else if(!digitalRead(NAVselectPin)){
    shm_bandmode = NAV_MODE;  
    encoderSteps = 100;
  }else{
    shm_bandmode = AM_MODE;
    encoderSteps = 1;
  }
  if(currentBandMode != shm_bandmode){  
    currentBandMode = shm_bandmode;
    SET_FREQ(EEPROMread(shm_bandmode, STANDBY_MEMSLOT), shm_standbyFreq);
    SET_FREQ(EEPROMread(shm_bandmode, ACTIVE_MEMSLOT), shm_activeFreq);
#define ENCODER_IMPULSES_PER_DETENT 2
    if(outerEncoder != NULL)
      delete outerEncoder;
    outerEncoder = new Encoder(OUTER_ENCODER_A_PIN, OUTER_ENCODER_B_PIN, ENCODER_IMPULSES_PER_DETENT, 1);
    if(innerEncoder != NULL)
      delete innerEncoder;
    innerEncoder = new Encoder(INNER_ENCODER_A_PIN, INNER_ENCODER_B_PIN, ENCODER_IMPULSES_PER_DETENT, encoderSteps);
#ifdef ENCODER_CONTROLLS_STANDBY
    innerEncoder->write(shm_standbyFreq.kHz);
    outerEncoder->write(shm_standbyFreq.MHz);
#else
    innerEncoder->write(shm_activeFreq.kHz);
    outerEncoder->write(shm_activeFreq.MHz);
#endif
    onFreqChange();
    if(shm_bandmode == AM_MODE){
      uint64_t LO = GET_FREQ(shm_activeFreq)*SI5351_FREQ_MULT*1000 - IF*SI5351_FREQ_MULT*1000;
      shm_si5351.set_freq(LO, SI5351_CLK0);
      Serial.print("SI5351 LO=");Serial.println(LO);
    }
    ATDD_RESET();
  }
}

void applyQueuedProperties(){
  if(!shm_ATDDOperational || !shm_ATDDReady || NULL == shm_propertiesQueue)
    return;

  struct setPropertyQueueElement* property = shm_propertiesQueue;
  shm_propertiesQueue = property->next;

  ATDD_SET_PROPERTY(property->property, property->value);
  Serial.print("property set ");Serial.println(property->property);
  shm_ATDDIRQ = 1;
  shm_ATDDReady = 0;

  free(property);
 
}

void setup() {
  //Clock output
  //Set clock output on PA7
  //Unfortunatelly the Nano Every does not expose that pin, so I have shorted it to the adjacent PB0 (and PB1 accidentally as well)
  //This means the 16Mhz clock is exposed on the digital 9 and 10 of the arduino 
  //CPU_CCP = CCP_IOREG_gc;
  //CLKCTRL.MCLKCTRLA |= CLKCTRL_CLKOUT_bm;
  //(No longer needed, got the crystal to work)
  pinMode(FMselectPin, INPUT_PULLUP);
  pinMode(COMselectPin, INPUT_PULLUP);
  pinMode(NAVselectPin, INPUT_PULLUP);

  pinMode(LED_BUILTIN, OUTPUT);
  pinMode(buttonPin, INPUT_PULLUP);
  pinMode(ATDD_RESET_PIN, OUTPUT);
  digitalWrite(LED_BUILTIN, LOW);
  shm_ATDDOperational = 0;
  shm_ATDDReady = 0;
  shm_AMStationDetected = 0;
  shm_ATDDIRQ = 0;
  


  Wire.begin();
  struct thread* firstThread;

  //Create a cyclic list
  threads = NULL;
  
  insertThread(createNewThread(updateDisplays, 100));
  firstThread = threads;
  insertThread(createNewThread(readEncoder, 10));
  insertThread(createNewThread(checkATTD, 50));
  insertThread(createNewThread(buttonDebounce, 50));
  insertThread(createNewThread(checkVolumePot, 10));
  insertThread(createNewThread(checkMode, 100));
  insertThread(createNewThread(checkEEPROM, 500));
  insertThread(createNewThread(applyQueuedProperties, 10));

  firstThread->next = threads;

  Serial.begin(9600);

  //Init ATDD IC 

  attachInterrupt(digitalPinToInterrupt(ATDD_IRQ_PIN), ATDDIHR, FALLING);
  //Wire.setClock(10000); 
  //For Nano Every
  // Formula is: BAUD = ((F_CLKPER/frequency) - F_CLKPER*T_RISE - 10)/2;
  // Where T_RISE varies depending on operating frequency...
  // From 1617 DS: 1000ns @ 100kHz / 300ns @ 400kHz / 120ns @ 1MHz
  uint32_t frequency = 10000;
  int16_t t_rise = 10000;
  uint32_t baud = ((F_CPU_CORRECTED/frequency) - (((F_CPU_CORRECTED*t_rise)/1000)/1000)/1000 - 10)/2;
  TWI0.MBAUD = (uint8_t)baud;


  delay(500);

  //Init LO IC
  while(!shm_si5351.init(SI5351_CRYSTAL_LOAD_8PF, 0, LO_PPM))
  {
    Serial.println("Clock generator not found on I2C bus!");
    delay(1000);
  }
  shm_si5351.update_status();
  shm_si5351.set_clock_disable(SI5351_CLK1, SI5351_CLK_DISABLE_HI_Z);
  shm_si5351.set_clock_disable(SI5351_CLK2, SI5351_CLK_DISABLE_HI_Z);
  shm_si5351.set_clock_pwr(SI5351_CLK1, 0);
  shm_si5351.set_clock_pwr(SI5351_CLK2, 0);
  
  checkMode();  

}

void loop() {
  unsigned long time;
  struct thread* thread = threads;

  while(1){
    time = millis();
    if(time - thread->lastExecuted > thread->target){
      thread->function();
      thread->lastExecuted = time;
    }
    thread = thread->next;
  }
}

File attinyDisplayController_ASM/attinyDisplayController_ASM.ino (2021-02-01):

#include "TinyWireS.h"
/**
 *   Attiny85 PINS
 *             ____
 *   RESET   -|_|  |- Vcc 
 * SH_CP (3) -|    |- (2) SCL
 * ST_CP (4) -|    |- (1) DS
 *   GND     -|____|- (0) SDA
 * 
 */

 
#define SLAVE_ACTIVE_ADDRESS 0x12
#define SLAVE_STNDBY_ADDRESS 0x13
#define DISPLAY_COUNT 6
#define SEGMENT_COUNT 8
#define I2C_REGISTER_COUNT 6
#define LATCH_PIN 4
#define CLOCK_PIN 3
#define DATA_PIN 1
#define CMD_LEN 2

uint8_t i2cRegisters[I2C_REGISTER_COUNT];

void i2cReceive(uint8_t bytes){
  if(bytes < CMD_LEN)
    return;
  do{
    uint8_t registerPos = (TinyWireS.receive() + 3 )% 6; //Swap the order of the displays
    i2cRegisters[registerPos] = TinyWireS.receive();

  }while((bytes -= CMD_LEN) > 0);
}

void setup() {
  pinMode(LATCH_PIN, OUTPUT);
  pinMode(CLOCK_PIN, OUTPUT);
  pinMode(DATA_PIN, OUTPUT);

  for(int i=0;i<I2C_REGISTER_COUNT; i++){
    i2cRegisters[i] = 0;
  }

  //Start with 0's on all displays
  for(int i=0; i<DISPLAY_COUNT; i++){
    i2cRegisters[i] = 0b11111100;
  }


  TinyWireS.begin(SLAVE_ACTIVE_ADDRESS);
  TinyWireS.onReceive(i2cReceive);
}

void loop() {

  for(int i=0; i<DISPLAY_COUNT; i++){
    /*
     * Segment remaping
     * 7|6|5|4|3|2|1|0  <-bits
     * A|B|C|D|E|F|G|DP
     * A|B|E|C|D|DP|G|F
     */
    
    register uint8_t segment;
    register uint8_t portb;
    register uint8_t us;
    asm volatile(
      "mov __tmp_reg__, __zero_reg__\n\t"
      "inc __tmp_reg__\n\t" //Set tmp_ret to 1, so we can lsl to select the segment

      "in %[portb], 0x18\n\t"  //Read portb and set clock_pin to 0
      //"cbr %[portb], %[clock_pin]\n\t"
      "cbr %[portb], 0x8\n\t" //CLOCK_PIN hardcoded as 0x8 !!!!
      
      "SEGMENT_LOOP_%=:"

      "mov %[segment], %[segments]\n\t"
      "and %[segment], __tmp_reg__\n\t"//Isolate the single segment we want to light up
      //LSByte
      //Bit 0
      "bst %[segment], 7\n\t"
      "bld %[portb], %[data_pin]\n\t"
      "out 0x18, %[portb]\n\t" 
      "sbi 0x18, %[clock_pin]\n\t"

      //Bit 1
      "bst %[segment], 6\n\t"
      "bld %[portb], %[data_pin]\n\t"
      "out 0x18, %[portb]\n\t" 
      "sbi 0x18, %[clock_pin]\n\t"
      
      //Bit 2
      "bst %[segment], 3\n\t"
      "bld %[portb], %[data_pin]\n\t"
      "out 0x18, %[portb]\n\t" 
      "sbi 0x18, %[clock_pin]\n\t"

      //Bit 3
      "bst %[segment], 5\n\t"
      "bld %[portb], %[data_pin]\n\t"
      "out 0x18, %[portb]\n\t" 
      "sbi 0x18, %[clock_pin]\n\t"

      //Bit 4
      "bst %[segment], 4\n\t"
      "bld %[portb], %[data_pin]\n\t"
      "out 0x18, %[portb]\n\t" 
      "sbi 0x18, %[clock_pin]\n\t"
      
      //Bit 5
      "bst %[segment], 0\n\t"
      "bld %[portb], %[data_pin]\n\t"
      "out 0x18, %[portb]\n\t" 
      "sbi 0x18, %[clock_pin]\n\t"
      
      //Bit 6
      "bst %[segment], 1\n\t"
      "bld %[portb], %[data_pin]\n\t"
      "out 0x18, %[portb]\n\t" 
      "sbi 0x18, %[clock_pin]\n\t"
      
      //Bit 7 Dont care
      "out 0x18, %[portb]\n\t" 
      "sbi 0x18, %[clock_pin]\n\t"

      //MSByte
      //Bit 0
      "bst %[disp], 0\n\t" 
      "bld %[portb], %[data_pin]\n\t"
      "out 0x18, %[portb]\n\t" 
      "sbi 0x18, %[clock_pin]\n\t"
     
      //Bit 1
      "bst %[disp], 1\n\t" 
      "bld %[portb], %[data_pin]\n\t"
      "out 0x18, %[portb]\n\t" 
      "sbi 0x18, %[clock_pin]\n\t"
      
      //Bit 2
      "bst %[disp], 2\n\t" 
      "bld %[portb], %[data_pin]\n\t"
      "out 0x18, %[portb]\n\t" 
      "sbi 0x18, %[clock_pin]\n\t"
      
      //Bit 3
      "bst %[disp], 3\n\t" 
      "bld %[portb], %[data_pin]\n\t"
      "out 0x18, %[portb]\n\t" 
      "sbi 0x18, %[clock_pin]\n\t"
      
      //Bit 4
      "bst %[disp], 4\n\t" 
      "bld %[portb], %[data_pin]\n\t"
      "out 0x18, %[portb]\n\t" 
      "sbi 0x18, %[clock_pin]\n\t"
      
      //Bit 5
      "bst %[disp], 5\n\t" 
      "bld %[portb], %[data_pin]\n\t"
      "out 0x18, %[portb]\n\t" 
      "sbi 0x18, %[clock_pin]\n\t"
      
      //Bit 6
      "bst %[segment], 2\n\t"
      "bld %[portb], %[data_pin]\n\t"
      "out 0x18, %[portb]\n\t" 
      "sbi 0x18, %[clock_pin]\n\t"
      
      //Bit 7 Dont care
      "out 0x18, %[portb]\n\t" 
      "sbi 0x18, %[clock_pin]\n\t"
      
      "sbi 0x18, %[latch_pin]\n\t" //latchHIGH
      "cbi 0x18, %[latch_pin]\n\t" //latchLOW

      //Loop to keep higher brightness and to smooth out difference in last segment
      //us = 0xc8 = 200
      //each loop takes 4 cycles, @16Mhz 4 cycles ~= 1/4us so execute 4*us
      //
      "ldi %[us], 0xc8\n\t"
      "busy1_%=: subi %[us],1\n\t" // 1 cycle
      "nop\n\t" //1 cycle
      "brne busy1_%=\n\t" // 2 cycles
      
      "ldi %[us], 0xc8\n\t"
      "busy2_%=: subi %[us],1\n\t" // 1 cycle
      "nop\n\t" //1 cycle
      "brne busy2_%=\n\t" // 2 cycles
      
      "ldi %[us], 0xc8\n\t"
      "busy3_%=: subi %[us],1\n\t" // 1 cycle
      "nop\n\t" //1 cycle
      "brne busy3_%=\n\t" // 2 cycles
      
      "ldi %[us], 0xc8\n\t"
      "busy4_%=: subi %[us],1\n\t" // 1 cycle
      "nop\n\t" //1 cycle
      "brne busy4_%=\n\t" // 2 cycles

      "lsl __tmp_reg__\n\t" // << until all 0s (sets carry to bit 7)
      "brcs END_%=\n\t" //Branch if carry
      "rjmp SEGMENT_LOOP_%=\n\t"
      "END_%=:nop\n\t"
    :
    [us] "=&a" (us),
    [portb] "=&a" (portb), 
    [segment] "=&a" (segment)
    :
    [segments] "a" (i2cRegisters[i]),
    [disp] "a" ((0x20 >> i)),
    [data_pin] "M" (DATA_PIN),
    [clock_pin] "M" (CLOCK_PIN),
    [latch_pin] "M" (LATCH_PIN)
    );

  }
  
  //Clear all displays
  register uint8_t clock_hi;
  register uint8_t clock_lo;
  asm volatile(
    //This shifts one 0 bit
    "cbi 0x18, %[clock_pin]\n\t"
    "cbi 0x18, %[data_pin]\n\t"
    "sbi 0x18, %[clock_pin]\n\t"
    "nop\n\t"
    "in %[clock_hi], 0x18\n\t"
    "mov %[clock_lo], %[clock_hi]\n\t"
    "bst __zero_reg__, 0\n\t"
    "bld %[clock_lo], %[clock_pin]\n\t"

    //LSByte
    //Bit 1
    "out 0x18, %[clock_lo]\n\t"
    "out 0x18, %[clock_hi]\n\t"
    //Bit 2
    "out 0x18, %[clock_lo]\n\t"
    "out 0x18, %[clock_hi]\n\t"
    //Bit 3
    "out 0x18, %[clock_lo]\n\t"
    "out 0x18, %[clock_hi]\n\t"
    //Bit 4
    "out 0x18, %[clock_lo]\n\t"
    "out 0x18, %[clock_hi]\n\t"
    //Bit 5
    "out 0x18, %[clock_lo]\n\t"
    "out 0x18, %[clock_hi]\n\t"
    //Bit 6
    "out 0x18, %[clock_lo]\n\t"
    "out 0x18, %[clock_hi]\n\t"

    "sbi 0x18, %[latch_pin]\n\t" //latchHIGH
    "cbi 0x18, %[latch_pin]\n\t" //latchLOW
    
  :
  [clock_hi] "=&a" (clock_hi),
  [clock_lo] "=&a" (clock_lo)
  :
  [data_pin] "M" (DATA_PIN),
  [clock_pin] "M" (CLOCK_PIN),
  [latch_pin] "M" (LATCH_PIN)
  );
  TinyWireS_stop_check();
}

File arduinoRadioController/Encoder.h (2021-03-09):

/* Encoder Library, for measuring quadrature encoded signals
 * http://www.pjrc.com/teensy/td_libs_Encoder.html
 * Copyright (c) 2011,2013 PJRC.COM, LLC - Paul Stoffregen <paul@pjrc.com>
 *
 * Version 1.2 - fix -2 bug in C-only code
 * Version 1.1 - expand to support boards with up to 60 interrupts
 * Version 1.0 - initial release
 * 
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
 * THE SOFTWARE IS PROVIDED "AS IS", WITHOUT WARRANTY OF ANY KIND, EXPRESS OR
 * IMPLIED, INCLUDING BUT NOT LIMITED TO THE WARRANTIES OF MERCHANTABILITY,
 * FITNESS FOR A PARTICULAR PURPOSE AND NONINFRINGEMENT. IN NO EVENT SHALL THE
 * AUTHORS OR COPYRIGHT HOLDERS BE LIABLE FOR ANY CLAIM, DAMAGES OR OTHER
 * LIABILITY, WHETHER IN AN ACTION OF CONTRACT, TORT OR OTHERWISE, ARISING FROM,
 * OUT OF OR IN CONNECTION WITH THE SOFTWARE OR THE USE OR OTHER DEALINGS IN
 * THE SOFTWARE.
 */


#ifndef Encoder_h_
#define Encoder_h_

#if defined(ARDUINO) && ARDUINO >= 100
#include "Arduino.h"
#elif defined(WIRING)
#include "Wiring.h"
#else
#include "WProgram.h"
#include "pins_arduino.h"
#endif

#include "utility/direct_pin_read.h"

#if defined(ENCODER_USE_INTERRUPTS) || !defined(ENCODER_DO_NOT_USE_INTERRUPTS)
#define ENCODER_USE_INTERRUPTS
#define ENCODER_ARGLIST_SIZE CORE_NUM_INTERRUPT
#include "utility/interrupt_pins.h"
#ifdef ENCODER_OPTIMIZE_INTERRUPTS
#include "utility/interrupt_config.h"
#endif
#else
#define ENCODER_ARGLIST_SIZE 0
#endif



// All the data needed by interrupts is consolidated into this ugly struct
// to facilitate assembly language optimizing of the speed critical update.
// The assembly code uses auto-incrementing addressing modes, so the struct
// must remain in exactly this order.
typedef struct {
	volatile IO_REG_TYPE * pin1_register;
	volatile IO_REG_TYPE * pin2_register;
	IO_REG_TYPE            pin1_bitmask;
	IO_REG_TYPE            pin2_bitmask;
	uint8_t                state;
	int32_t                position;
} Encoder_internal_state_t;

class Encoder
{
private:
	uint8_t hardware_steps;
	uint8_t software_steps;
public:
	Encoder(uint8_t pin1, uint8_t pin2) {
		Encoder(pin1, pin2, 1, 1);
	}
	Encoder(uint8_t pin1, uint8_t pin2, uint8_t hstep, uint8_t sstep) {
		hardware_steps = hstep;
		software_steps = sstep;
		#ifdef INPUT_PULLUP
		pinMode(pin1, INPUT_PULLUP);
		pinMode(pin2, INPUT_PULLUP);
		#else
		pinMode(pin1, INPUT);
		digitalWrite(pin1, HIGH);
		pinMode(pin2, INPUT);
		digitalWrite(pin2, HIGH);
		#endif
		encoder.pin1_register = PIN_TO_BASEREG(pin1);
		encoder.pin1_bitmask = PIN_TO_BITMASK(pin1);
		encoder.pin2_register = PIN_TO_BASEREG(pin2);
		encoder.pin2_bitmask = PIN_TO_BITMASK(pin2);
		encoder.position = 0;
		// allow time for a passive R-C filter to charge
		// through the pullup resistors, before reading
		// the initial state
		delayMicroseconds(2000);
		uint8_t s = 0;
		if (DIRECT_PIN_READ(encoder.pin1_register, encoder.pin1_bitmask)) s |= 1;
		if (DIRECT_PIN_READ(encoder.pin2_register, encoder.pin2_bitmask)) s |= 2;
		encoder.state = s;
#ifdef ENCODER_USE_INTERRUPTS
		interrupts_in_use = attach_interrupt(pin1, &encoder);
		interrupts_in_use += attach_interrupt(pin2, &encoder);
#endif
		//update_finishup();  // to force linker to include the code (does not work)
	}


#ifdef ENCODER_USE_INTERRUPTS
	inline int32_t read() {
		if (interrupts_in_use < 2) {
			noInterrupts();
			update(&encoder);
		} else {
			noInterrupts();
		}
		int32_t ret = encoder.position;
		interrupts();
		ret = (ret / hardware_steps)*software_steps;
		return ret;
	}
	inline int32_t readAndReset() {
		if (interrupts_in_use < 2) {
			noInterrupts();
			update(&encoder);
		} else {
			noInterrupts();
		}
		int32_t ret = encoder.position;
		encoder.position = 0;
		interrupts();
		ret = (ret / hardware_steps)*software_steps;
		return ret;
	}
	inline void write(int32_t p) {
		noInterrupts();
		encoder.position = (p*hardware_steps/software_steps);
		interrupts();
	}
#else
	inline int32_t read() {
		update(&encoder);
		return encoder.position/hardware_steps;
	}
	inline int32_t readAndReset() {
		update(&encoder);
		int32_t ret = encoder.position/hardware_steps;
		encoder.position = 0;
		return ret;
	}
	inline void write(int32_t p) {
		encoder.position = p*hardware_steps;
	}
#endif
private:
	Encoder_internal_state_t encoder;
#ifdef ENCODER_USE_INTERRUPTS
	uint8_t interrupts_in_use;
#endif
public:
	static Encoder_internal_state_t * interruptArgs[ENCODER_ARGLIST_SIZE];
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

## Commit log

2021-01-11 Added fritzing drafts
    [7segx3_test.fzz, LogicLevelConverter.fzz, transistorDemultiplexer.fzz]
2021-01-31 working ASM ATtiny code
    [BOM_display.csv, I1.fzz, I3.fzz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]
2021-02-12 Added 3dprints and exposing nano every clock to ATDD
    [EncoderSupport .FCStd, EncoderSupport.stl, FrontPanelV1.FCStd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]
2021-02-16 3d models for working radio
    [displayTest.stl, frontPanelV2.stl, potSupport.blend]
2021-02-17 volume pot
    [testPanel.stl]
2021-03-09 soldering radio
    [radioPCBv1.fzz, radioWIP.fzz]
2021-06-01 fixed tuning of LO
    [arduinoRadioController.ino]
2021-06-01 Added initial prototype pictures
2021-07-21 Added schematics for amplifier and main radio circuits
    [All.blend, amplifier.sch, radio.kicad_pcb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]
2021-07-21 Added schematics for displays and downconverter
    [displayModule.kicad_pcb, displayModule.sch, downConverter.kicad_pcb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]
2021-07-22 improved radio and amplifier schematic
    [radio.sch]
2021-07-24 Power supply modifications
    [amplifier.sch, radio.sch]
2021-07-30 Begin work on display module printed pcb order
    [displayModule.sch]
2021-09-10 Only activate squelch after AM transmission is picked up
    [displayModule.kicad_pcb, displayModule.sch, displayModule_beta1.kicad_pcb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]
